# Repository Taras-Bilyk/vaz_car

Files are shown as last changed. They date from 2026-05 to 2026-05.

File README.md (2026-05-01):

# VAZ 2107 RC CAR

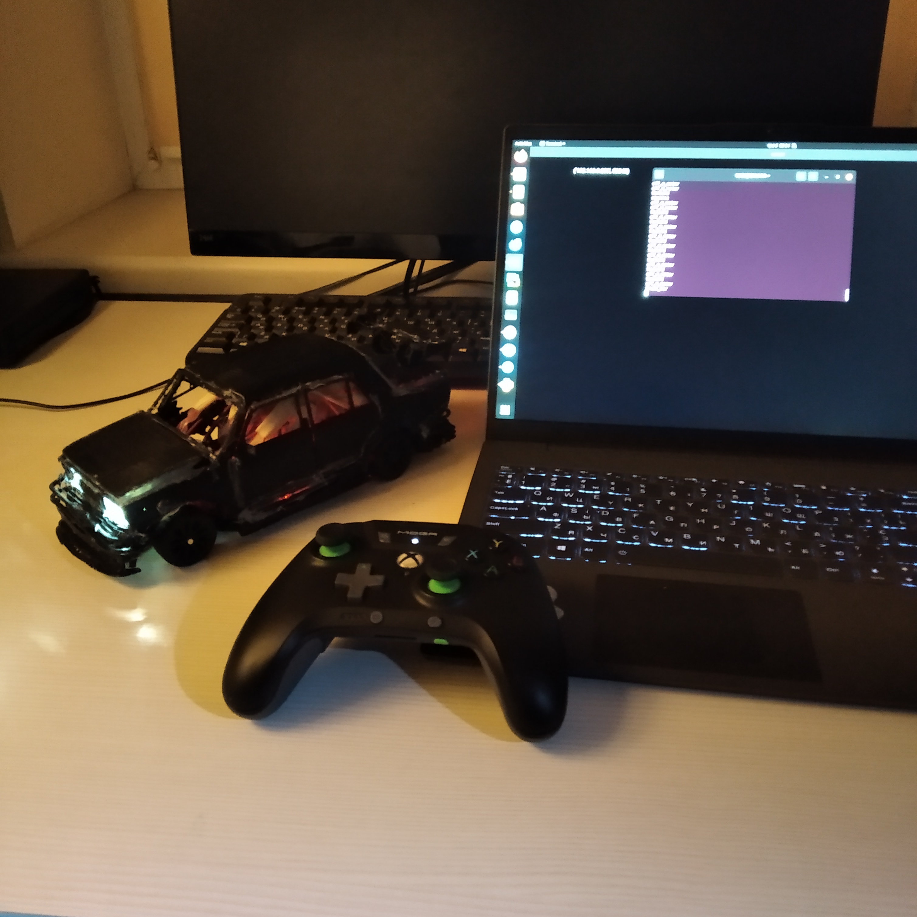
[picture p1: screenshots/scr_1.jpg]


## 🤨 Навіщо ?:
просто цікавий проект

## 🤓 Опис:
це міні модель машини на керуванні по WIFI мережі з джостика

## ☠️ Використані технології:
- прошивка на MICROPYTHON
- GUI сервера на KIVY
- під капотом працює на UDP SOCKETS
- події джостика сервер читає через PYGAME
- 3D моделювання в BLENDER
- слайсинг в ULTIMAKER CURA
- 3D FDM друк
- пайка електричної схеми

## 🌱 Структура проекта:
- `screenshots/` — скріншоти і фотографії
- `stl_objects/` - 3D модельки, які можна надрукувати повторно
- `server.py` — головний файл для запуска сервера
- `main.py` — головний файл прошивки

## 😇 Фічі:
- підключенн стабільне на всій площі покриття WIFI
- біле ближнє світло
- дальнє біле світло
- жовті блимаючі поворотники
- жовта блимаюча аварійка
- задні білі вогні при русі назад
- задні червоні габарити
- червоні яскраві стоп сигнали при нажатті на тормоз
- задній привід (1 мотор нан кожному задньому колесі, сумарно 2)
- на передніх колесах стоять сервомотори для поворотім (1 мотор на кожному передньому колесі, сумарно 2)
- рух вперед
- рух назад
- повороти

## 🌚 Компоненти які для збірки:
- ESP32-WROOM (1x)
- щітковий звичайний мотор на 5-7 вольт (2х)
- сервомотори MG90 Micro Servo (2х)
- понижувач LM2596 струму (2х)
- акумулятор на 7.4 вольта (1х)
- дроти
- пприпой
- червоні світлодіоди (2х)
- білі світлодіоди (6х)
- жовті світлодіоди (4х)
- драйвери моторів L298N (2х)

## 🥺 Принцип роботи:
- джостик передає дані про натиснення на ноутбук
- сервер на ноуттбуці обробляє ці сигнали і відправляє команди по WIFI на ESP32 (тобто машинку)
- ESP32 виконує ті команди які вона отримує по WIFI

## ⚠️ ПОПЕРЕДЖЕННЯ:
- прошивка працює ЛИШЕ на ESP32-WROOM

## 😎 Як це запустити ?:
1. встановлюємо необхідні пакети на пк/ноутбук
```bash
sudo apt update
sudo apt install python3
sudo apt install python3-pip python3-dev libsdl2-dev libsdl2-image-dev libsdl2-mixer-dev libsdl2-ttf-dev libportmidi-dev libswscale-dev libavformat-dev libavcodec-dev zlib1g-dev libgstreamer1.0-0 gstreamer1.0-plugins-base gstreamer1.0-plugins-good
pip install "kivy[base]"
sudo pip3 install adafruit-ampy
```
2. змінюємо ось ці рядки в файлі `main.py` на ваші дані:
```python
wifi_module.connect('YOUR_WIFI_SSID', 'YOUR_WIFI_PWD')
ip_of_computer = 'YOUR_IP_OF_PC_WHERE_SERVER_IS_RUNNING'
```
4. заисуємо прошивку на ESP32
```bash
ampy --port /dev/ttyUSB0 put main.py
```
4. вмикаємо машину кнопкою на дверях
5. підключаємо джостик до пк/ноута
6. запускаємо сервер
```bash
python3 server.py
```
7. машина підключиться автоматично

## ✨ А ось так це все виглядає в реальному житті
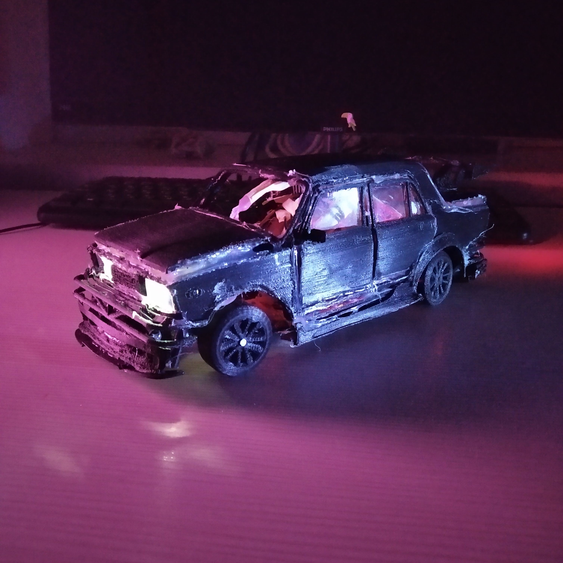
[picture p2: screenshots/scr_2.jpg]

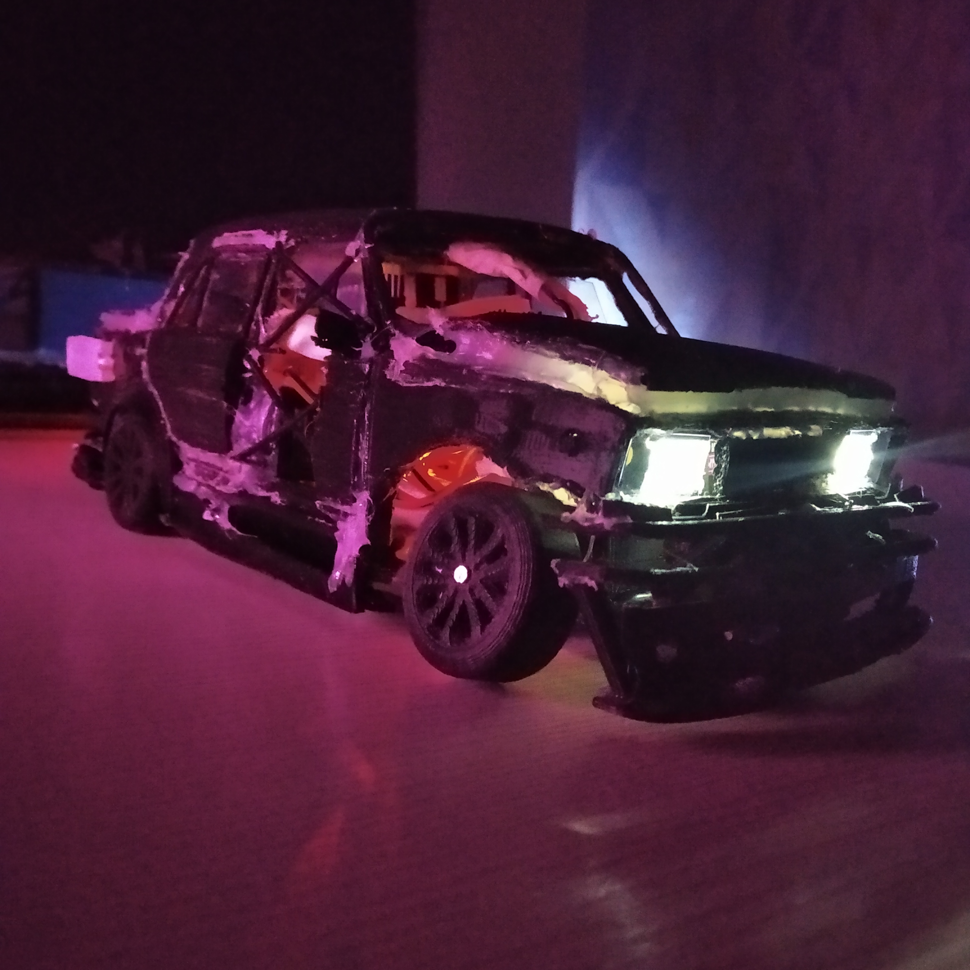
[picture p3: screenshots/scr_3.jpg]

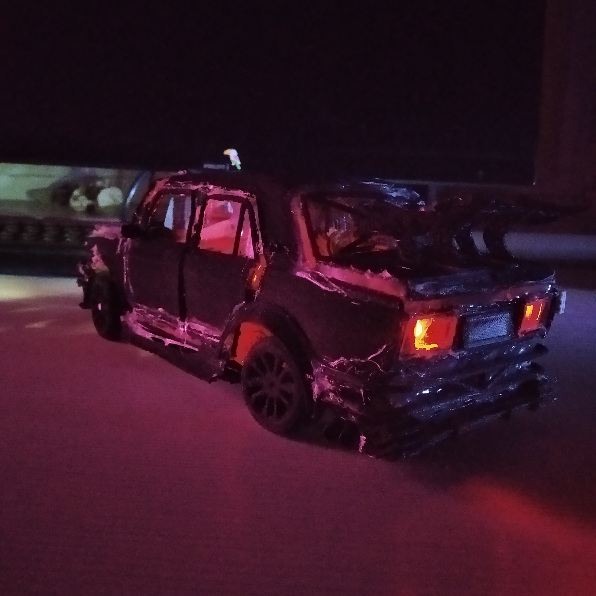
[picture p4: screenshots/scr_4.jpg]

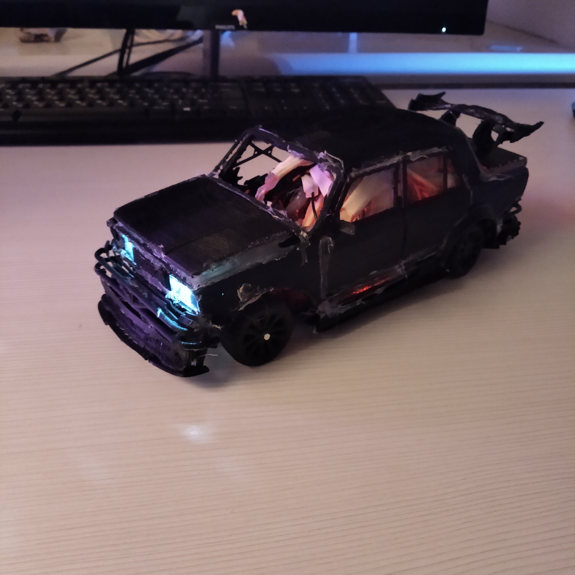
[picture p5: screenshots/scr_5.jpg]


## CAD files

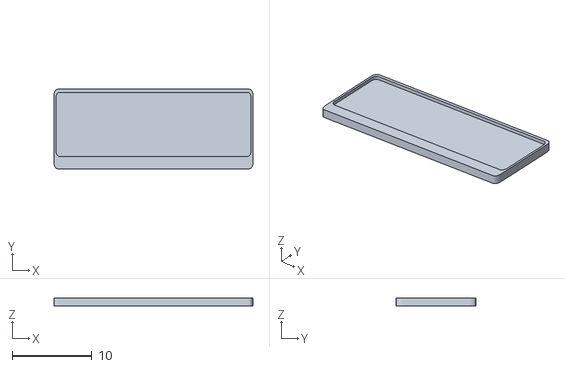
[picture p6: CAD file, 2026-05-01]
stl_objects/licence_plate.stl
25.0 x 10.0 x 1.00

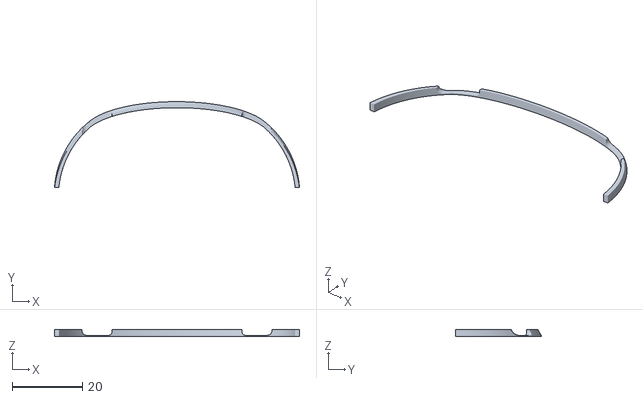
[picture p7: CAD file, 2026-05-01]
stl_objects/bamper_front.stl
70.0 x 24.5 x 2.00

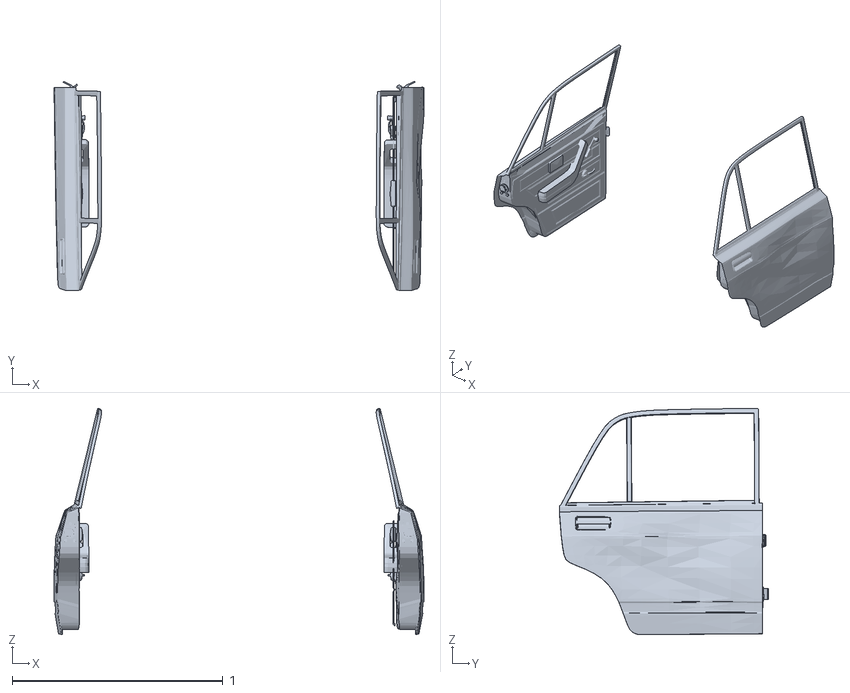
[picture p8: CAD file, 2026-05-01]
stl_objects/doors_back.stl
1.76 x 0.995 x 1.07

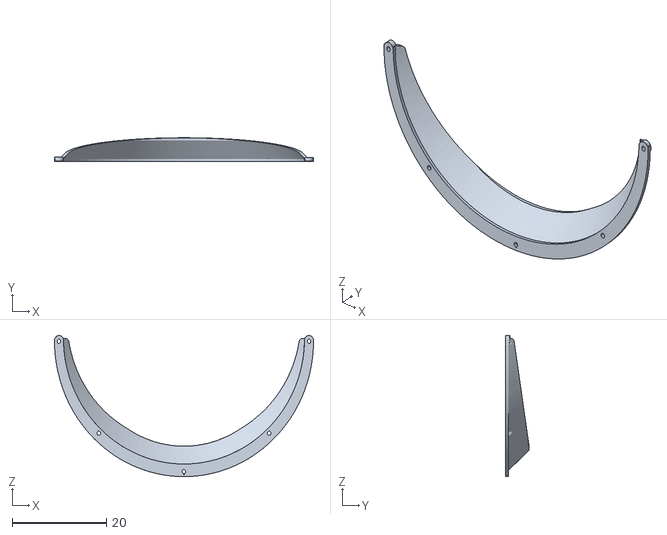
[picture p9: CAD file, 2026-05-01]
stl_objects/arch.stl
55.0 x 5.00 x 30.0

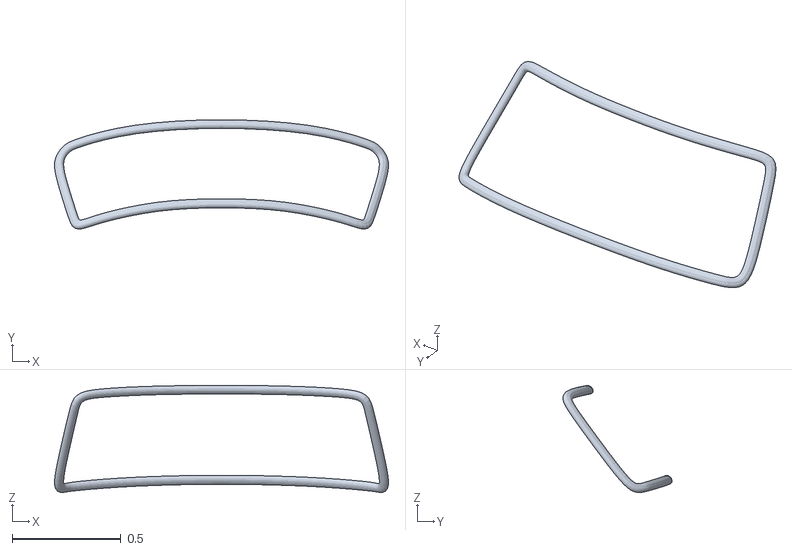
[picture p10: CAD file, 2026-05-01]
stl_objects/window_frame_front.stl
1.53 x 0.503 x 0.492

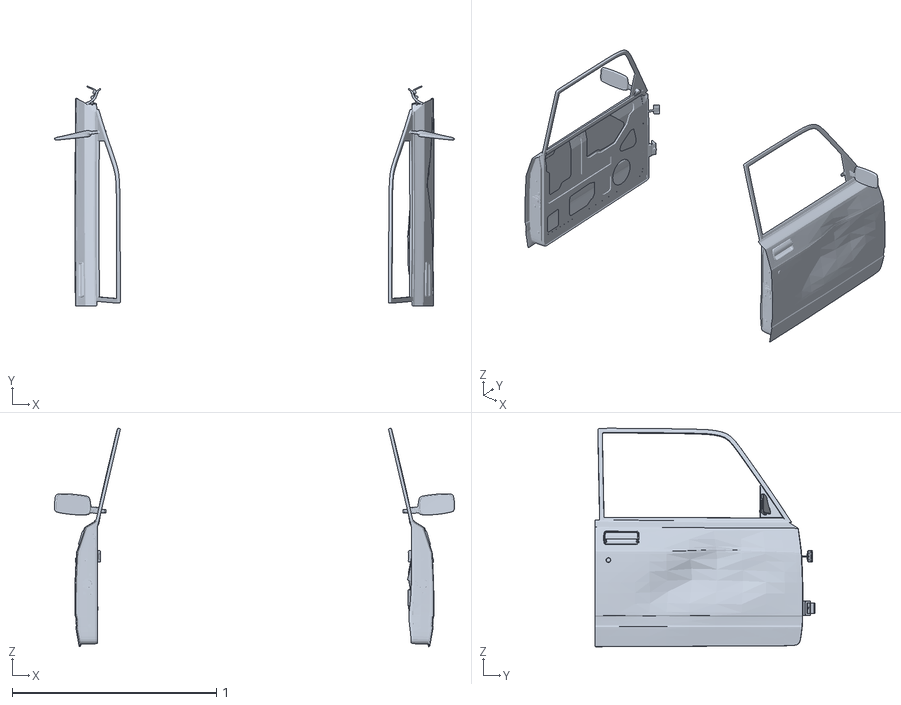
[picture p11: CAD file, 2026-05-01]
stl_objects/doors_front.stl
1.96 x 1.08 x 1.07

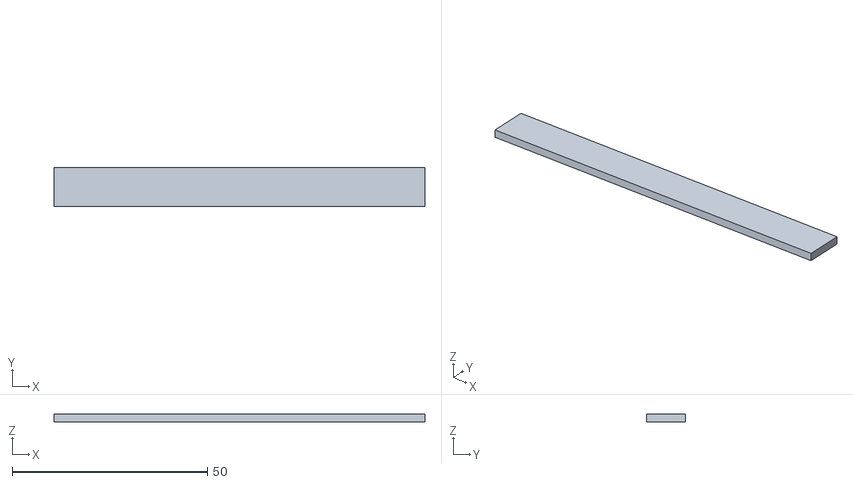
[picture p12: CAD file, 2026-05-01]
stl_objects/splitter_right_bottom.stl
95.0 x 10.0 x 2.00

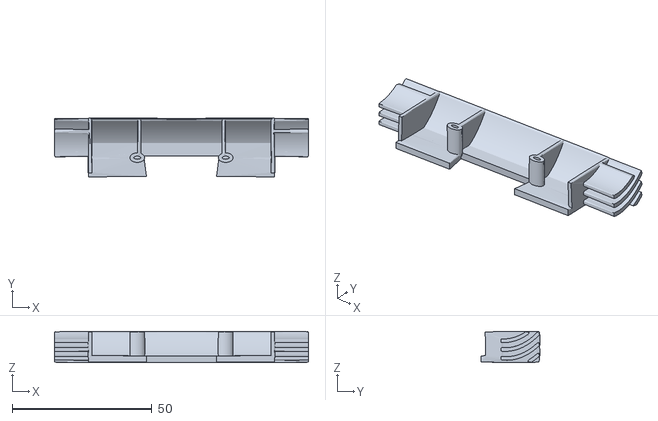
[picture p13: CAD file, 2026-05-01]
stl_objects/splitter_back.stl
90.9 x 20.9 x 11.2

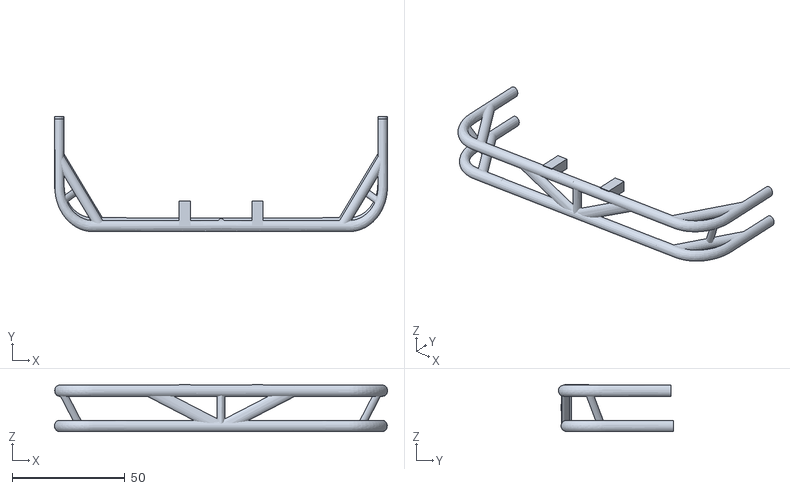
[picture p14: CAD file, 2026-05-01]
stl_objects/bamper_front_back.stl
147.9 x 51.2 x 20.9

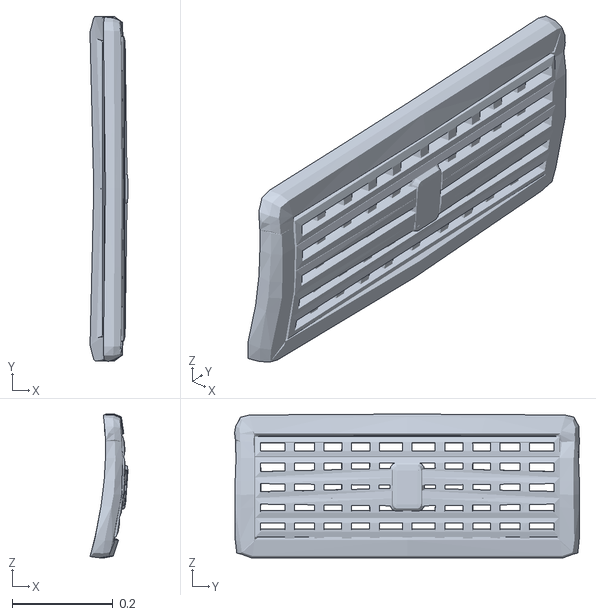
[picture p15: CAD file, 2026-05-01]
stl_objects/radiator.stl
0.0754 x 0.684 x 0.285

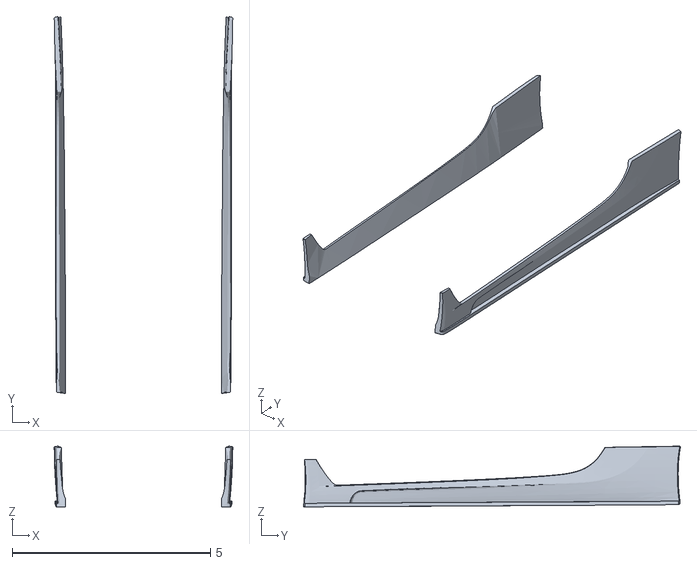
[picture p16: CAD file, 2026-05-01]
stl_objects/splitter_side.stl
4.50 x 9.50 x 1.53

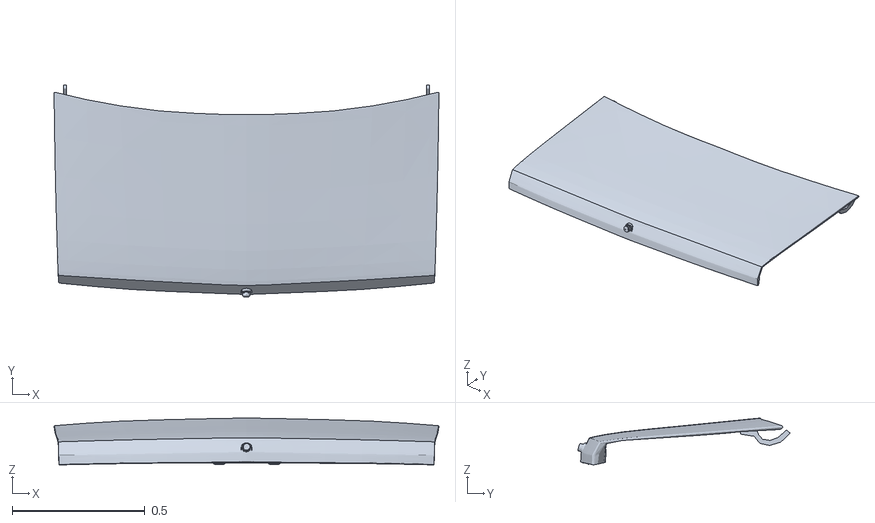
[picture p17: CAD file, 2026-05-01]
stl_objects/bagaznik.stl
1.45 x 0.799 x 0.176

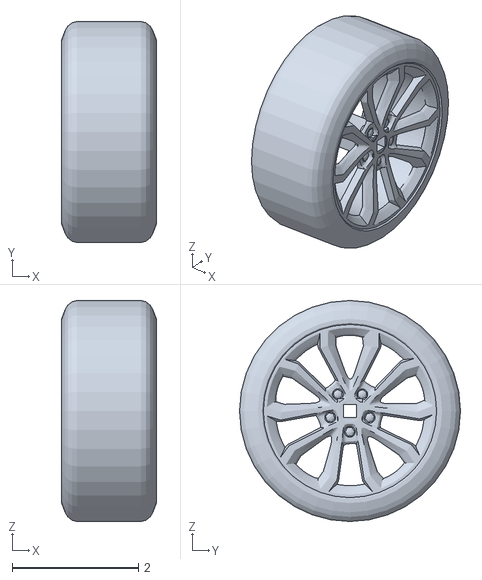
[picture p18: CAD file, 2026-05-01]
stl_objects/wheel.stl
1.50 x 3.50 x 3.50

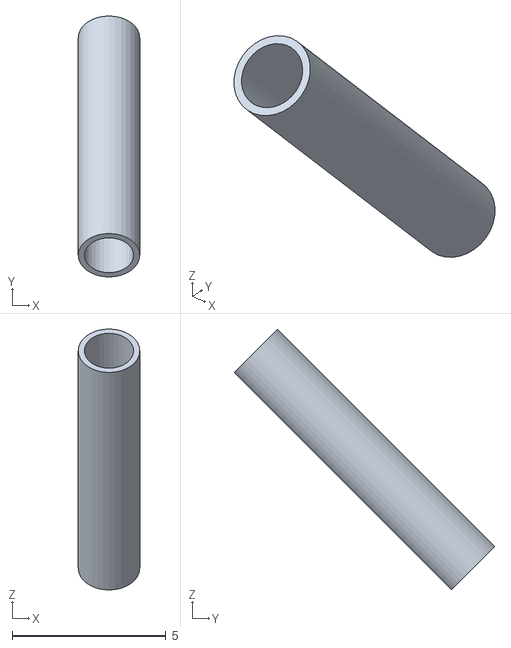
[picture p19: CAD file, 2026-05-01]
stl_objects/exh_back.stl
2.00 x 8.49 x 8.49

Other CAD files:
stl_objects/bamper_a.stl
stl_objects/splitter_left_bottom.stl
stl_objects/base_bottom.stl
stl_objects/kapot.stl
stl_objects/base_body.stl
stl_objects/cross_window.stl
stl_objects/inc_front.stl
stl_objects/wheel_v2.stl

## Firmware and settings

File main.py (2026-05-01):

from machine import Pin, PWM # type: ignore
import network # type: ignore
import _thread
import socket
import time

# motor speed ( max duty 1023 )
steering_motor_1 = PWM(Pin(15), freq = 50)
steering_motor_2 = PWM(Pin(13), freq = 50)
pwm_move_motor_1_speed = PWM(Pin(4), freq = 1000)
pwm_move_motor_2_speed = PWM(Pin(27), freq = 1000)
pwm_move_motor_1_speed.duty(1023)
pwm_move_motor_2_speed.duty(1023)

# motor direction pins
motor_1_dir_pin_0 = Pin(16, Pin.OUT)
motor_1_dir_pin_1 = Pin(17, Pin.OUT)
motor_2_dir_pin_0 = Pin(14, Pin.OUT)
motor_2_dir_pin_1 = Pin(12, Pin.OUT)

# set start main motors direction
motor_1_dir_pin_0.value(0)
motor_1_dir_pin_1.value(0)
motor_2_dir_pin_0.value(0)
motor_2_dir_pin_1.value(0)

# lights turns
light_front_left_yellow = PWM(Pin(0), freq = 1000)
light_front_right_yellow = PWM(Pin(2), freq = 1000)
light_back_left_yellow = PWM(Pin(5), freq = 1000)
light_back_right_yellow = PWM(Pin(18), freq = 1000)
light_front_left_yellow.duty(0)
light_front_right_yellow.duty(0)
light_back_left_yellow.duty(0)
light_back_right_yellow.duty(0)

# back white
light_back_left_white = PWM(Pin(22), freq = 1000)
light_back_right_white = PWM(Pin(23), freq = 1000)
light_back_left_white.duty(0)
light_back_right_white.duty(0)

# for main lights
light_front_pin_0 = Pin(19, Pin.OUT)
light_front_pin_1 = Pin(21, Pin.OUT)
light_back_pin_0= Pin(32, Pin.OUT)
light_back_pin_1 = Pin(33, Pin.OUT)
light_front_pin_0.value(0)
light_front_pin_1.value(0)
light_back_pin_0.value(0)
light_back_pin_1.value(0)

# main lights
light_front_white_main = PWM(Pin(26), freq = 1000)
light_back_red_main = PWM(Pin(25), freq = 1000)
light_front_white_main.duty(50)
light_back_red_main.duty(50)

# connect to server
wifi_module = network.WLAN(network.STA_IF)
wifi_module.active(True)
wifi_module.connect('YOUR_WIFI_SSID', 'YOUR_WIFI_PWD')
ip_of_computer = 'YOUR_IP_OF_PC_WHERE_SERVER_IS_RUNNING'
port = 14888
connected_to_server = 0
s = None

def connection_to_server():
    global connected_to_server, s
    if connected_to_server == 0:
        try:
            if s:
                s.close()
            s = socket.socket()
            s.connect((ip_of_computer, port))
            connected_to_server = 1
        except:
            connected_to_server = 0
            if s:
                s.close()
            s = None
def ping_sending():
    global s
    global connected_to_server
    try:
        s.send(b'ping')
    except:
        connected_to_server = 0
        if s != None:
            s.close()
        s = None
#================================================================

def set_angle(angle):
    min_pulse = 0.5
    max_pulse = 2.5
    period = 20
    pulse_width = min_pulse + (max_pulse - min_pulse) * (angle / 180)
    duty = int((pulse_width / period) * 1023)
    steering_motor_1.duty(duty)
    steering_motor_2.duty(duty)

blinking_avar = 0
time_counter = 0
blink_left = 0
blink_right = 0
light_r_now = 0

def start_avar():
    global blinking_avar
    if blinking_avar == 1:
        if time_counter % 2 == 0:
            light_front_left_yellow.duty(1023)
            light_front_right_yellow.duty(1023)
            light_back_left_yellow.duty(1023)
            light_back_right_yellow.duty(1023)
        else:
            light_front_left_yellow.duty(0)
            light_front_right_yellow.duty(0)
            light_back_left_yellow.duty(0)
            light_back_right_yellow.duty(0)
def stop_blink():
    global blinking_avar, blink_left, blink_right
    blinking_avar = 0
    blink_left = 0
    blink_right = 0
    light_front_left_yellow.duty(0)
    light_front_right_yellow.duty(0)
    light_back_left_yellow.duty(0)
    light_back_right_yellow.duty(0)
def is_blink_left():
    global blink_left
    if blink_left == 1:
        if time_counter % 2 == 0:
            light_front_left_yellow.duty(1023)
            light_front_right_yellow.duty(0)
            light_back_left_yellow.duty(1023)
            light_back_right_yellow.duty(0)
        else:
            light_front_left_yellow.duty(0)
            light_front_right_yellow.duty(0)
            light_back_left_yellow.duty(0)
            light_back_right_yellow.duty(0)
def is_blink_right():
    global blink_right
    if blink_right == 1:
        if time_counter % 2 == 0:
            light_front_left_yellow.duty(0)
            light_front_right_yellow.duty(1023)
            light_back_left_yellow.duty(0)
            light_back_right_yellow.duty(1023)
        else:
            light_front_left_yellow.duty(0)
            light_front_right_yellow.duty(0)
            light_back_left_yellow.duty(0)
            light_back_right_yellow.duty(0)
def action(command_paremeter):
    global blinking_avar, blink_left, blink_right, light_r_now
    if command_paremeter == 'forward':
        motor_1_dir_pin_0.value(0)
        motor_1_dir_pin_1.value(1)
        motor_2_dir_pin_0.value(1)
        motor_2_dir_pin_1.value(0)
        light_back_left_white.duty(0)
        light_back_right_white.duty(0)
    if command_paremeter == 'reverse':
        motor_1_dir_pin_0.value(1)
        motor_1_dir_pin_1.value(0)
        motor_2_dir_pin_0.value(0)
        motor_2_dir_pin_1.value(1)
        light_back_left_white.duty(1023)
        light_back_right_white.duty(1023)
    if command_paremeter == 'off_m_motor':
        motor_1_dir_pin_0.value(0)
        motor_1_dir_pin_1.value(0)
        motor_2_dir_pin_0.value(0)
        motor_2_dir_pin_1.value(0)
    if command_paremeter == 't_left':
        set_angle(60)
    if command_paremeter == 't_right':
        set_angle(120)
    if command_paremeter == 'off_t_motor':
        set_angle(90)
    if command_paremeter == 'on_light_f':
        light_front_pin_1.value(1)
        light_front_white_main.duty(50)
    if command_paremeter == 'off_light_f':
        light_front_pin_1.value(0)
    if command_paremeter == 'front_far':
        light_front_pin_1.value(1)
        light_front_white_main.duty(300)
    if command_paremeter == 'on_bl_l':
        blink_left = 1
    if command_paremeter == 'on_bl_r':
        blink_right = 1
    if command_paremeter == 'off_bl':
        stop_blink()
    if command_paremeter == 'blink_avar':
        blinking_avar = 1
    if command_paremeter == 'off_light_r':
        light_back_pin_0.value(0)
        light_back_pin_1.value(0)
        light_r_now = 0
    if command_paremeter == 'on_light_r':
        light_back_pin_0.value(0)
        light_back_pin_1.value(1)
        light_r_now = 1
    if command_paremeter == 'start_braking':
        motor_1_dir_pin_0.value(1)
        motor_1_dir_pin_1.value(1)
        motor_2_dir_pin_0.value(1)
        motor_2_dir_pin_1.value(1)
        light_back_pin_0.value(0)
        light_back_pin_1.value(1)
        light_back_red_main.duty(300)
    if command_paremeter == 'stop_braking':
        motor_1_dir_pin_0.value(0)
        motor_1_dir_pin_1.value(0)
        motor_2_dir_pin_0.value(0)
        motor_2_dir_pin_1.value(0)
        light_back_red_main.duty(50)
        if light_r_now == 0:
            light_back_pin_0.value(0)
            light_back_pin_1.value(0)
def receive_message_from_server():
    global connected_to_server, s
    while 1:
        if connected_to_server == 1:
            try:
                message_from_server_in_bites = s.recv(1024)
                if not message_from_server_in_bites:
                    connected_to_server = 0
                    s.close()
                    s = None
                    continue
                message_from_server = message_from_server_in_bites.decode()

                #====== actions ======
                commands = message_from_server.strip().split('\n')
                for command in commands:
                    action(command)
                #===================
            except:
                connected_to_server = 0
                if s:
                    s.close()
                s = None
    time.sleep(0.1)
_thread.start_new_thread(receive_message_from_server, ())
def main():
    global time_counter
    connection_to_server()
    ping_sending()
    time_counter += 1
    start_avar()
    is_blink_left()
    is_blink_right()
    time.sleep(0.5)

while 1:
    main()

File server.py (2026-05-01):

from kivy.app import App
from kivy.uix.floatlayout import FloatLayout
from kivy.uix.label import Label
from kivy.core.window import Window
from kivy.clock import Clock
import threading
import socket
import time
import pygame

class serverApp(App):
    def build(self):
        pygame.init()
        pygame.joystick.init()
        try:
            self.joystick = pygame.joystick.Joystick(0)
            self.joystick.init()
            print('j connected')
        except Exception:
            print('j not connected')
        Clock.schedule_interval(self.check_j, 0.1)
        self.is_avar = 0
        self.is_blink_left = 0
        self.is_blink_right = 0
        self.left = 0
        self.right = 0
        self.streight = 0
        Window.bind(on_key_down=self.click_envent)
        Window.bind(on_key_up=self.release_event)
        #====== interface ======
        self.main_layout = FloatLayout()
        self.label_with_ip_of_connected_device = Label(text = 'server listening...',
                                                        color = (1, 1, 1, 1),
                                                        font_size=20,
                                                        size_hint=(.3, .1),
                                                        pos_hint={'x': 0, 'y': .9})
        self.main_layout.add_widget(self.label_with_ip_of_connected_device)
        #======================
        self.host = '0.0.0.0'
        self.port = 14888
        self.is_server_listening = 0
        self.listen_process = threading.Thread(target = self.listen)
        self.listen_process.daemon = True
        self.listen_process.start()
        self.get_data_from_client = threading.Thread(target = self.listen_connected_device)
        self.get_data_from_client.daemon = True
        self.get_data_from_client.start()
        return self.main_layout

    def listen(self):
        while 1:
            if self.is_server_listening == 0:
                self.label_with_ip_of_connected_device.text = 'server listening...'
                self.s = socket.socket()
                self.s.setsockopt(socket.SOL_SOCKET, socket.SO_REUSEADDR, 1)
                self.s.bind((self.host, self.port))
                self.s.listen(1)
                self.conn, self.addr = self.s.accept()
                self.conn.settimeout(10)
                self.label_with_ip_of_connected_device.text = str(self.addr)
                self.is_server_listening = 1
                self.get_data_from_client = threading.Thread(target=self.listen_connected_device)
                self.get_data_from_client.daemon = True
                self.get_data_from_client.start()
            time.sleep(0.5)
    def send_message_to_connected_device(self, data):
        if self.is_server_listening == 1:
            self.conn.send((str(data)+'\n').encode())
    def listen_connected_device(self):
        while 1:
            if self.is_server_listening == 1:
                try:
                    self.data_from_client_in_bites = self.conn.recv(1024)
                    if not self.data_from_client_in_bites:
                        self.label_with_ip_of_connected_device.text = 'server listening...'
                        self.is_server_listening = 0
                        try:
                            self.conn.close()
                        except:
                            pass
                        self.conn = None
                        self.addr = None
                        continue
                    self.data_from_connected_device = self.data_from_client_in_bites.decode()
                    self.label_with_ip_of_connected_device.text = str(self.addr)
                    self.is_server_listening = 1
                except socket.timeout:
                    self.label_with_ip_of_connected_device.text = 'server listening...'
                    self.is_server_listening = 0
                    try:
                        self.conn.close()
                    except:
                        pass
                    self.conn = None
                    self.addr = None
                except:
                    pass
            time.sleep(0.5)
#=======================================


    def release_event(self, window, key, scancode):
        if key == 119 or key == 115:
            self.send_message_to_connected_device('off_m_motor')
        if key == 97 or key == 100:
            self.send_message_to_connected_device('off_t_motor')
        if key == 120:
            self.send_message_to_connected_device('stop_braking')

    def click_envent(self, window, key, scancode, codepoint, modifier):
        self.command_to_push = ''
        if codepoint == 'w':
            self.command_to_push = 'forward'
        if codepoint == 's':
            self.command_to_push = 'reverse'
        if codepoint == 'a':
            self.command_to_push = 't_left'
        if codepoint == 'd':
            self.command_to_push = 't_right'
        if codepoint == '1':
            self.command_to_push = 'off_light_f'
        if codepoint == '2':
            self.command_to_push = 'on_light_f'
        if codepoint == '3':
            self.command_to_push = 'front_far'
        if codepoint == '4':
            self.command_to_push = 'off_light_r'
        if codepoint == '5':
            self.command_to_push = 'on_light_r'
        if codepoint == 'q':
            self.command_to_push = 'off_bl'
            if self.is_blink_left == 0:
                self.command_to_push = 'on_bl_l'
                self.is_blink_left = 1
            else:
                self.command_to_push = 'off_bl'
                self.is_blink_left = 0
        if codepoint == 'e':
            self.command_to_push = 'off_bl'
            if self.is_blink_right == 0:
                self.command_to_push = 'on_bl_r'
                self.is_blink_right = 1
            else:
                self.command_to_push = 'off_bl'
                self.is_blink_right = 0
        if codepoint == 'z':
            self.command_to_push = 'off_bl'
        if codepoint == 't':
            self.command_to_push = 'off_bl'
            if self.is_avar == 0:
                self.command_to_push = 'blink_avar'
                self.is_avar = 1
            else:
                self.command_to_push = 'off_bl'
                self.is_avar = 0
        if codepoint == 'x':
            self.command_to_push = 'start_braking'
        if self.command_to_push != '':
            self.send_message_to_connected_device(self.command_to_push)
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
